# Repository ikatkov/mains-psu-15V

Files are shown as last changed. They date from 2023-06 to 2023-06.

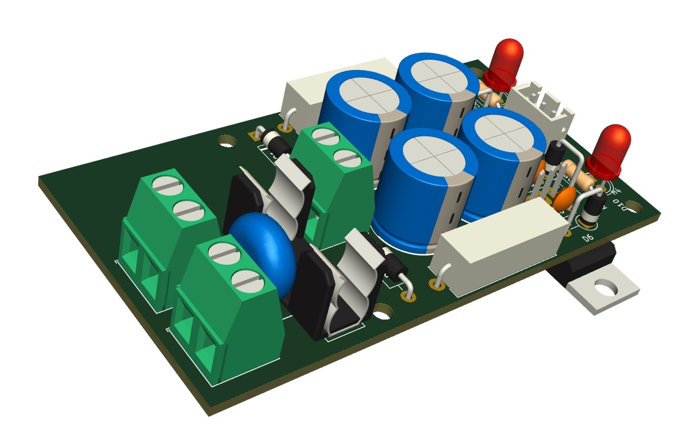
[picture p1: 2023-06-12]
3d-top.jpg

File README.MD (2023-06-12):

The simplest possible mains PSU
I needed one for the used Tektronix active probe (p6201) I bought off ebay.

The PSU take 120V mains and outputs +/- 15V, 175mA max (each rail)
I added varistor, 250mA fuse on the input and 15V zeners on the output.

If one tries to draw more current, the mains ripple appears on the output.

See LTSpice folder for the sim files.
See Kicad folder for schematic/pcb layout

Interesting bits:

* It is a full wave voltage dubler PSU. https://sound-au.com/project05-mini.htm
This is rather unfortunate, but the transformer I salvaged only had ~17VAC, this is not enough for the more conventional type with a full wave bridge rectifier. The price is much larger input caps and extra heat that is burned when voltage is regulated down to +/- 15V.

* Two LEDs are here to signal that both rails are healthy and bleed off these large resistors. If a regulator shutdowns (over current, overheating) corresponding LED goes off.

* Large, 2W 3 Ohm resistors are there to burn heat, and reduce the heat dissipation requirments for the voltage regulator. I did not have smaller, 2W rated, ones. If I did - the PSU could either use smaller caps, or product larger output current.

* Since this is not a switching PSU, not extra filtering is needed. Not backfeed filtering is needed either.

* I use aluminum enclosure as a heat sink. Regulators are connected by wires to the PCB and screwed right to the aluminum.

* For the enclosure - I saw a large salvaged box one in halfs, 3d printed a PETG cap where IEC AC socket and AC main switch are mounted.

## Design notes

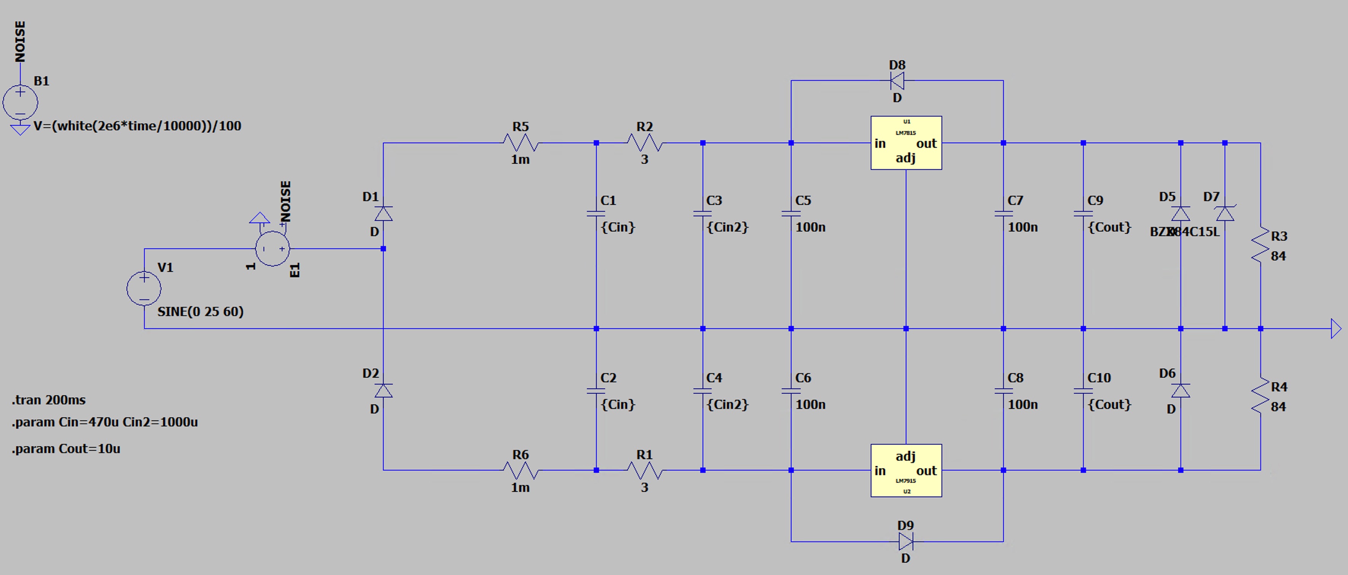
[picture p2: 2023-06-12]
lt-spice-sim.jpg

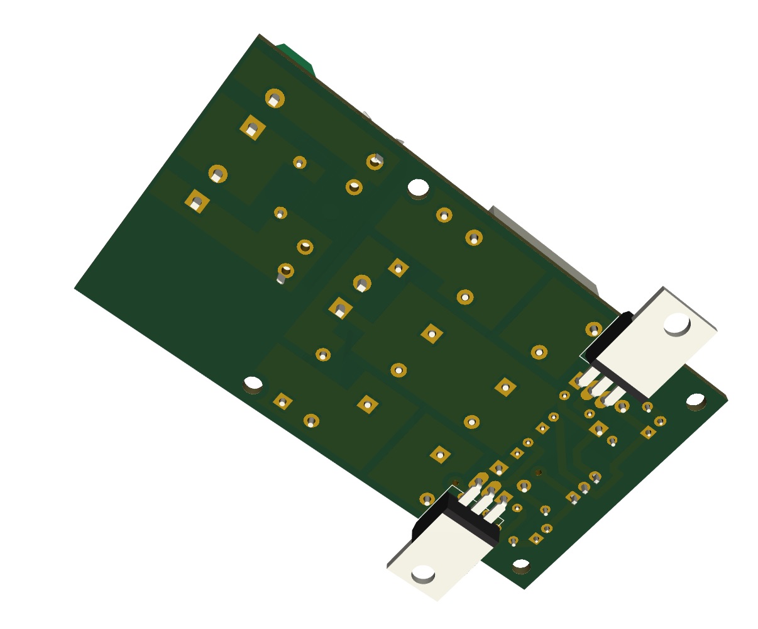
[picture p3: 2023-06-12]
3d-bottom.jpg

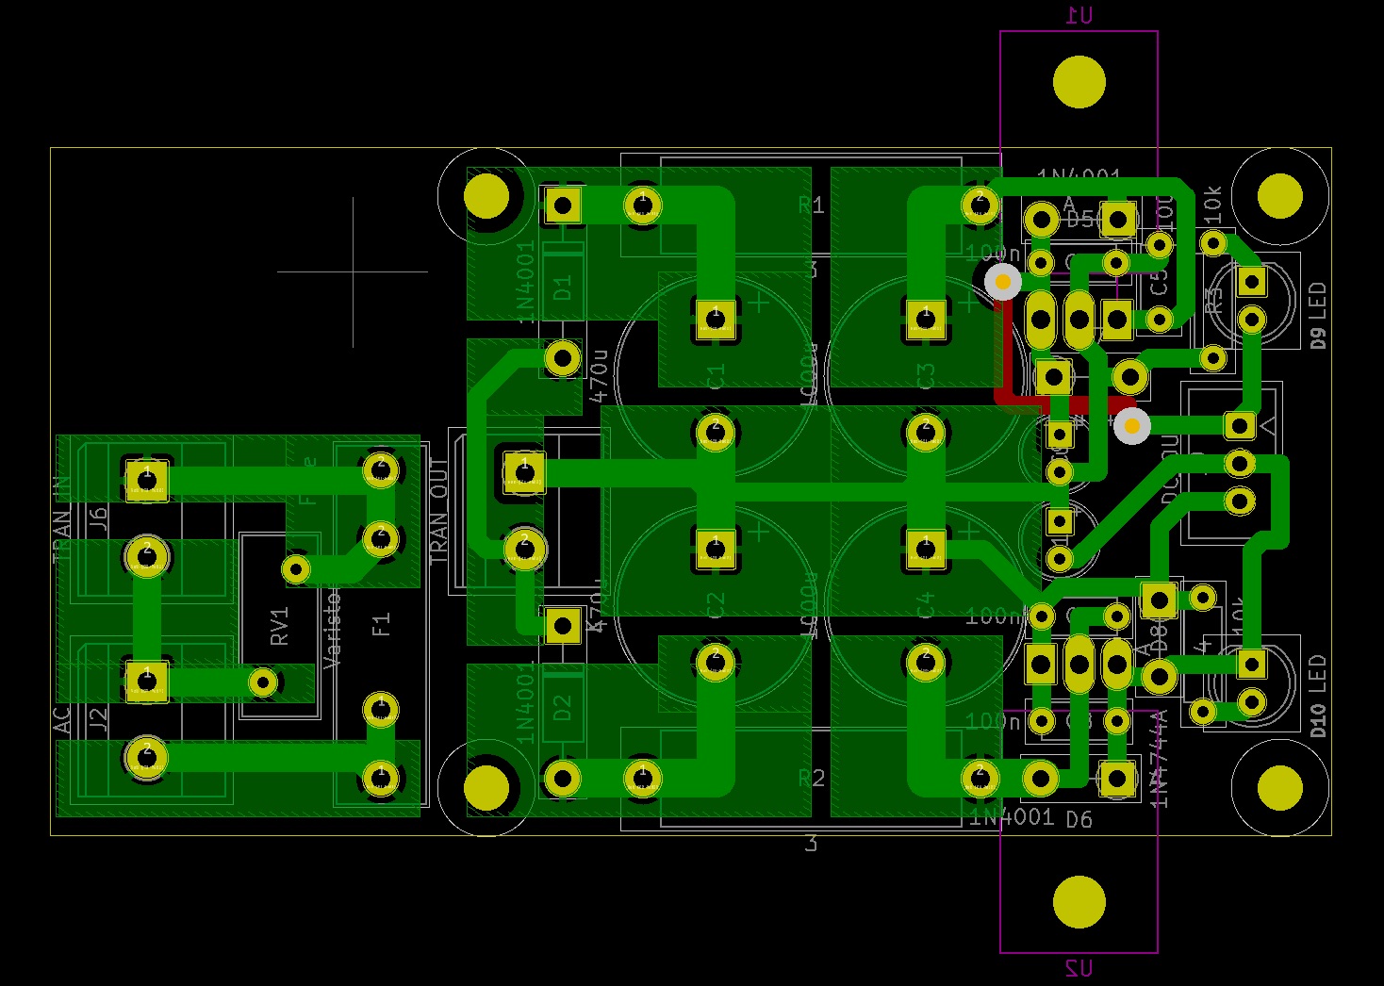
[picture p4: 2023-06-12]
layout.jpg

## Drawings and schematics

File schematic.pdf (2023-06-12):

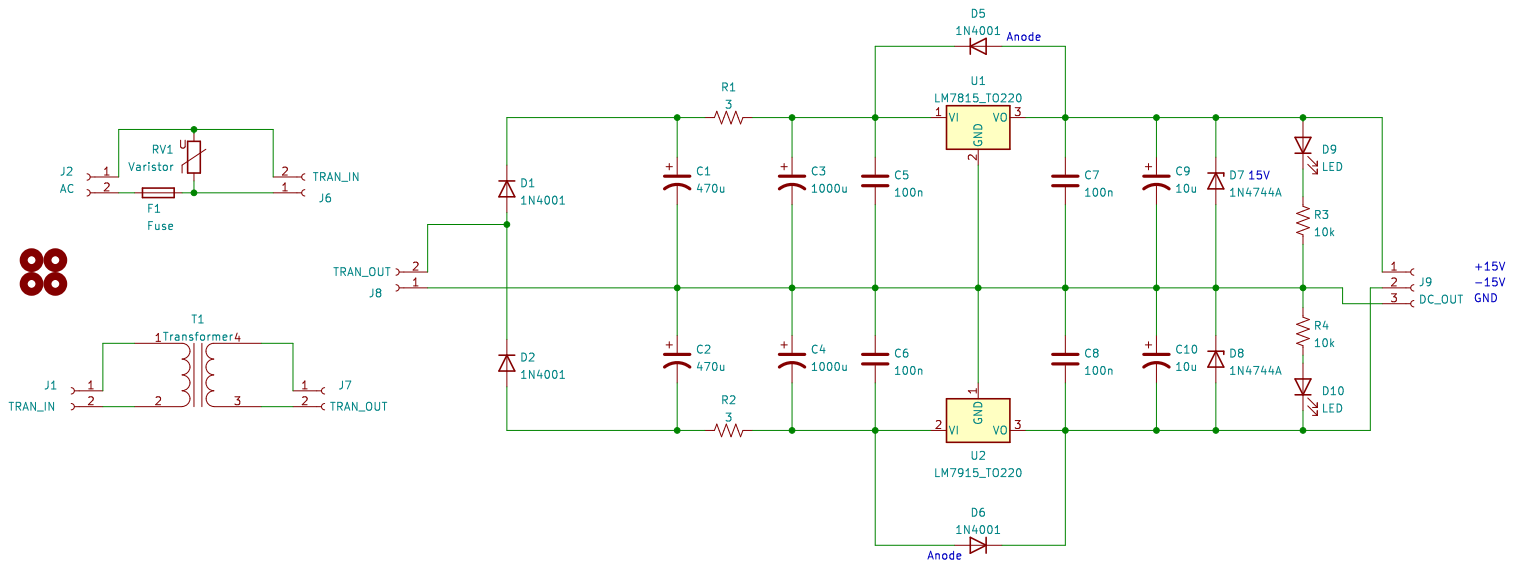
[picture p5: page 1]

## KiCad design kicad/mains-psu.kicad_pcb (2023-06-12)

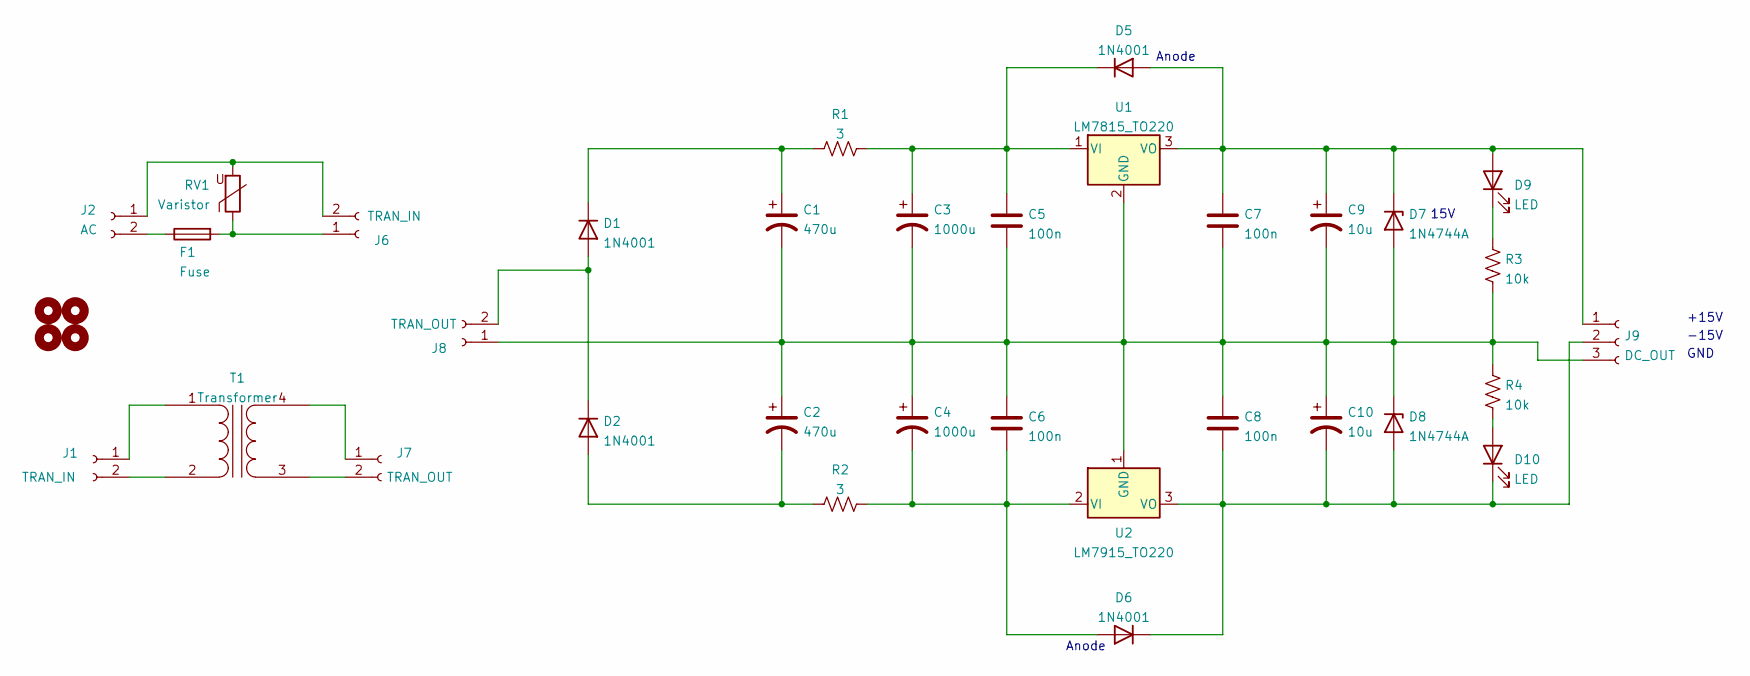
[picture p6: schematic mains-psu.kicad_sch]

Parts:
C1, C2: 470u; CP_Radial_D13.0mm_P7.50mm
C3, C4: 1000u; CP_Radial_D13.0mm_P7.50mm
C5, C6, C7, C8: 100n; C_Disc_D5.0mm_W2.5mm_P5.00mm
C9, C10: 10u; CP_Radial_D5.0mm_P2.50mm
D1, D2: 1N4001; D_DO-41_SOD81_P10.16mm_Horizontal
D5, D6: 1N4001; D_DO-41_SOD81_P5.08mm_Vertical_AnodeUp
D7, D8: 1N4744A; D_DO-41_SOD81_P5.08mm_Vertical_AnodeUp
D9, D10: LED; LED_D5.0mm
F1: Fuse; Fuseholder_Littelfuse_100_series_5x20mm
H1, H2, H3, H4: MountingHole; MountingHole_3mm
J1: TRAN_IN
J2: AC; TerminalBlock_Phoenix_MKDS-1,5-2-5.08_1x02_P5.08mm_Horizont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
J6: TRAN_IN; TerminalBlock_Phoenix_MKDS-1,5-2-5.08_1x02_P5.08mm_Horizont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
J7: TRAN_OUT
J8: TRAN_OUT; TerminalBlock_Phoenix_MKDS-1,5-2-5.08_1x02_P5.08mm_Horizont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
J9: DC_OUT; JST_XH_B3B-XH-A_1x03_P2.50mm_Vertical
R1, R2: 3; R_Axial_Power_L20.0mm_W6.4mm_P22.40mm
R3, R4: 10k; R_Axial_DIN0207_L6.3mm_D2.5mm_P7.62mm_Horizontal
RV1: Varistor; RV_Disc_D12mm_W5mm_P7.5mm
T1: Transformer
U1: LM7815_TO220; TO-220F-3_Horizontal_TabDown
U2: LM7915_TO220; TO-220F-3_Horizontal_TabDown

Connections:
unnamed: C1.1, D1.1 (K), R1.1
unnamed: C1.2, C2.1, C3.2, C4.1, C5.2, C6.1, C7.2, C8.1, C9.2, C10.1, D7.2 (A), D8.1 (K), J8.1, J9.3, R3.1, R4.2, U1.2 (GND), U2.1 (GND)
unnamed: C2.2, D2.2 (A), R2.1
unnamed: C3.1, C5.1, D5.1 (K), R1.2, U1.1 (VI)
unnamed: C4.2, C6.2, D6.2 (A), R2.2, U2.2 (VI)
unnamed: C7.1, C9.1, D5.2 (A), D7.1 (K), D9.2 (A), J9.1, U1.3 (VO)
unnamed: C8.2, C10.2, D6.1 (K), D8.2 (A), D10.1 (K), J9.2, U2.3 (VO)
unnamed: D1.2 (A), D2.1 (K), J8.2
unnamed: D9.1 (K), R3.2
unnamed: D10.2 (A), R4.1
unnamed: F1.1, J2.2
unnamed: F1.2, J6.1, RV1.1
unnamed: J1.1, T1.1 (AA)
unnamed: J1.2, T1.2 (AB)
unnamed: J2.1, J6.2, RV1.2
unnamed: J7.1, T1.4 (SB)
unnamed: J7.2, T1.3 (SA)

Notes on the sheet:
+15V
Anode
GND
-15V
15V

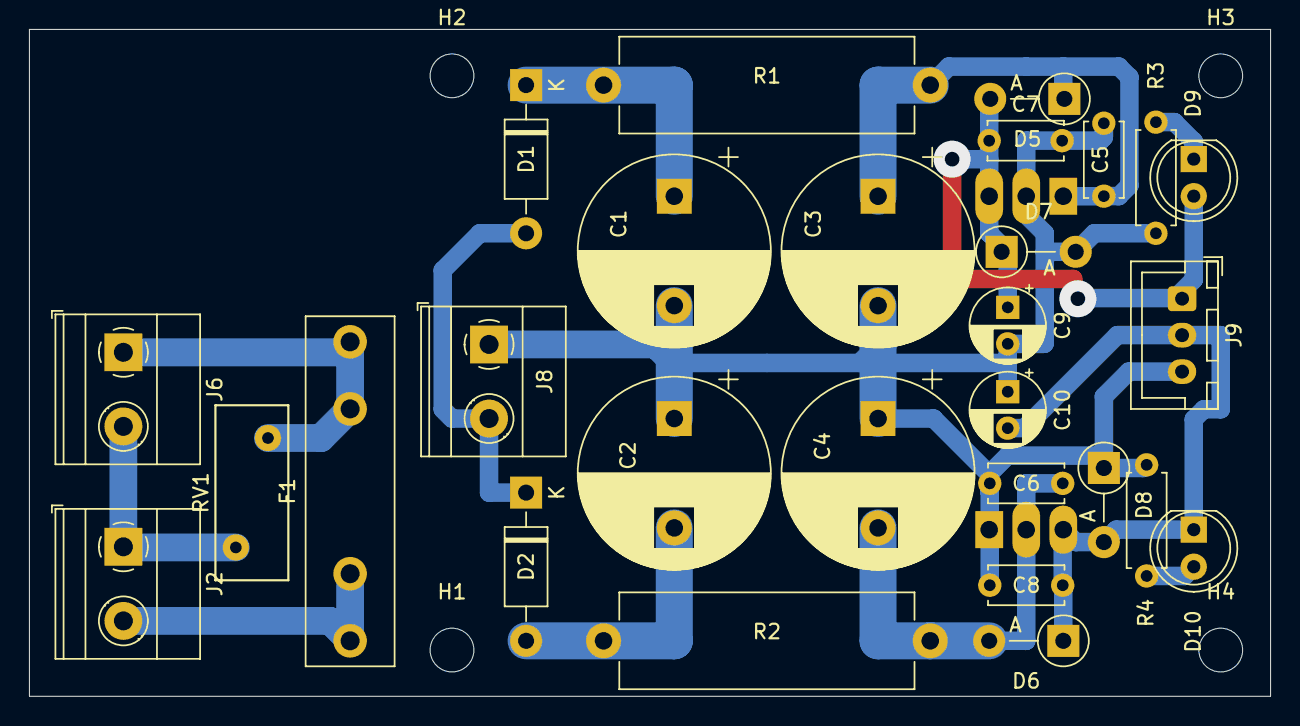
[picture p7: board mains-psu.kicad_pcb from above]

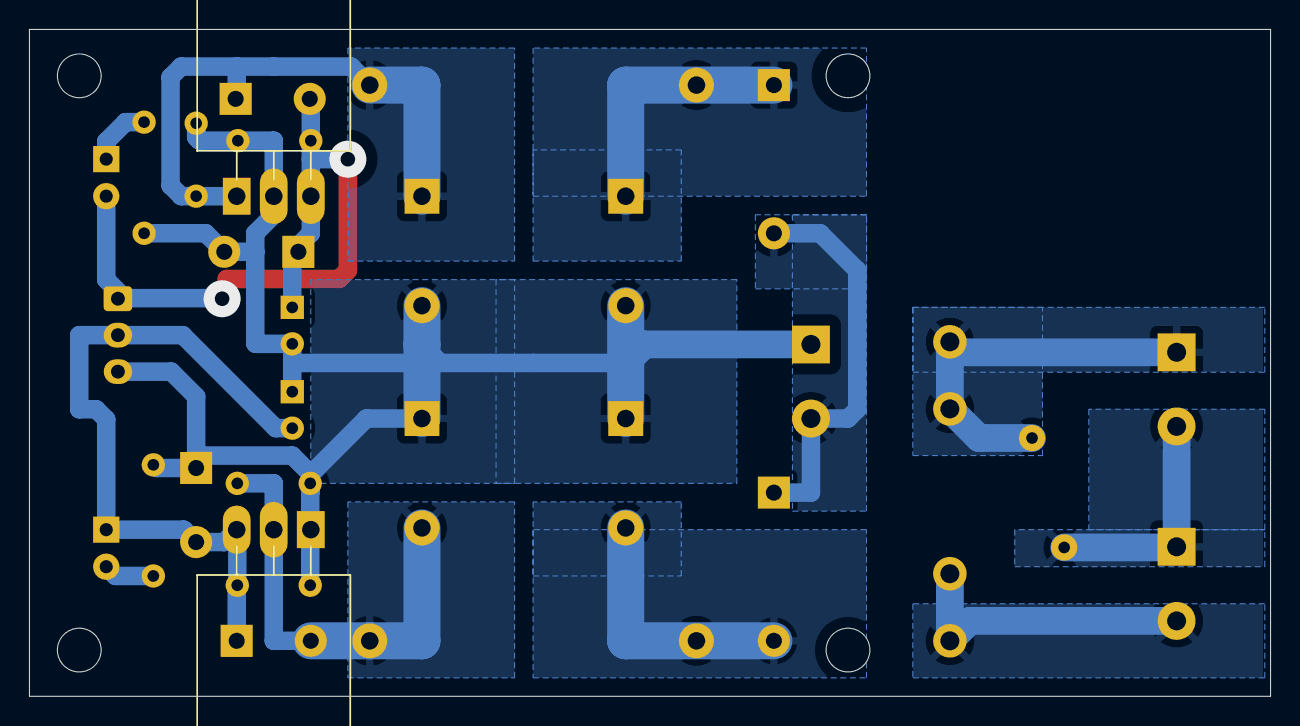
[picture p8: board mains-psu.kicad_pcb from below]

Board: 4 copper layers, 85.1 x 45.7 mm, 34 parts (2 on the bottom side), 13 nets.
